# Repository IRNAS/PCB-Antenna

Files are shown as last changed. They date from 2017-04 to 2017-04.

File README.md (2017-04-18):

# PCB Antenna
#### Compact Wideband Omnidirectional UHF Antenna for TV White Space Cognitive Radio Application

This repository contains the design files for PCB antenna. PCB Antena is described in the [given PDF][link1_paper_PDF], and it is designed using [Altium designer EDA tool][link2_altium].

For more information about the design of the antenna please see the **[Schematics and PCB design files in PDF format][link3_design_PDF]**.

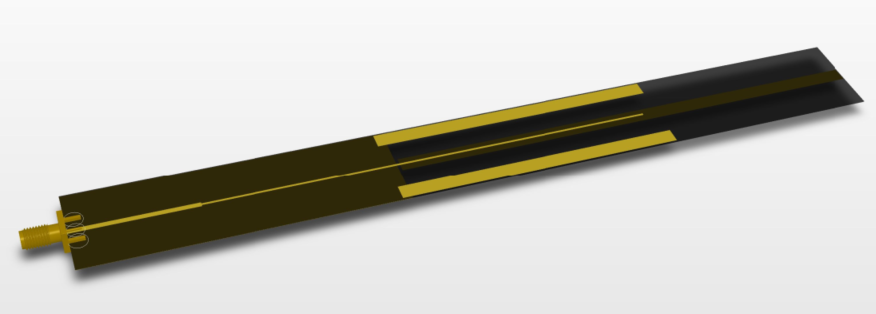
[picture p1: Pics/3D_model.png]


---

#### License

All our projects are as usefully open-source as possible.

Hardware including documentation is licensed under [CERN OHL v.1.2. license](http://www.ohwr.org/licenses/cern-ohl/v1.2)

Firmware and software originating from the project are licensed under [GNU GENERAL PUBLIC LICENSE v3](http://www.gnu.org/licenses/gpl-3.0.en.html).

Open data generated by our projects is licensed under [CC0](https://creativecommons.org/publicdomain/zero/1.0/legalcode).

All our websites and additional documentation are licensed under [Creative Commons Attribution-ShareAlike 4 .0 Unported License] (https://creativecommons.org/licenses/by-sa/4.0/legalcode).

What this means is that you can use hardware, firmware, software and documentation without paying a royalty and knowing that you'll be able to use your version forever. You are also free to make changes but if you share these changes then you have to do so on the same conditions that you enjoy.

Koruza, GoodEnoughCNC, and IRNAS are all names and marks of Institut IRNAS Race. 
You may use these names and terms only to attribute the appropriate entity as required by the Open Licences referred to above. You may not use them in any other way and in particular, you may not use them to imply endorsement or authorization of any hardware that you design, make or sell.

[link1_paper_PDF]: https://github.com/IRNAS/PCB-Antenna/blob/master/Docs/Design%20guide/manuscript.pdf
[link2_altium]: http://www.altium.com/
[link3_design_PDF]: https://github.com/IRNAS/PCB-Antenna/blob/master/pcb-antenna-PCB/Project%20Outputs%20for%20PCB_Project/pcb_antenna.PDF

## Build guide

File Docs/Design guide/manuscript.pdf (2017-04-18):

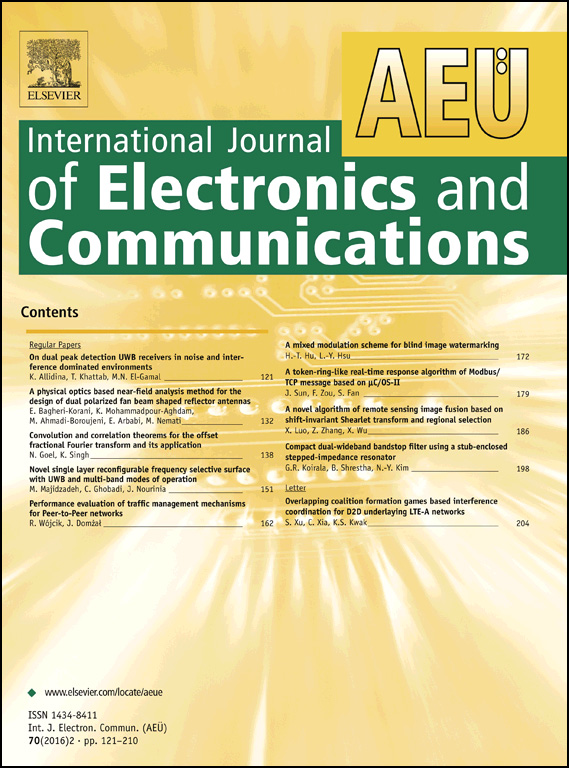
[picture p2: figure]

# Accepted Manuscript

# Short communication

# Compact Wideband Omnidirectional UHF Antenna for TV White Space Cognitive Radio Application

# Naizhi Wang, Yue Gao, Qingsheng Zeng

PII: | S1434-8411(16)30990-6
DOI: | http://dx.doi.org/10.1016/j.aeue.2017.02.011
Reference: | AEUE 51803
To appear in: | International Journal of Electronics and Communi-
| cations
Received Date: | 23 November 2016
Revised Date: | 16 January 2017
Accepted Date: | 12 February 2017

Please cite this article as: N. Wang, Y. Gao, Q. Zeng, Compact Wideband Omnidirectional UHF Antenna for TV White Space Cognitive Radio Application, International Journal of Electronics and Communications (2017), doi:

# http://dx.doi.org/10.1016/j.aeue.2017.02.011

This is a PDF file of an unedited manuscript that has been accepted for publication. As a service to our customers we are providing this early version of the manuscript. The manuscript will undergo copyediting, typesetting, and review of the resulting proof before it is published in its final form. Please note that during the production process errors may be discovered which could affect the content, and all legal disclaimers that apply to the journal pertain.

1

### Compact Wideband Omnidirectional UHF Antenna for TV White Space

### Cognitive Radio Application

### Naizhi Wang¹*, Yue Gao²

### , Qingsheng Zeng³,4

1
The 14th Research Institute of China Electronics Technology Group Corporation, Nanjing

210039, P. R. China, e-mail: naizhiwang@hotmail.com

2
School of Electronic Engineering and Computer Science, Queen Mary University of

London, London E1 4NS, U.K.

3
School of Physics and Electronic Engineering, Shanxi University, Taiyuan 030006, P. R.

China

4
School of Electrical Engineering and Computer Science, University of Ottawa, Ottawa

K1N 6N5, Canada

*
Corresponding author

This paper presents design and analysis of a compact wideband omnidirectional antenna for application in

TV white space cognitive radio. The proposed antenna mainly consists of a monopole, a pair of parasitic

elements, and a brief impedance matching network, all etched on an FR4 substrate. To obtain physical

insight, an equivalent circuit is modelled and analysed to reveal the contribution of each part of the

antenna to its bandwidth enhancement. Performance of the antenna is evaluated by simulations, and then

further validated by experiments. Experimental results show that the antenna has an impedance bandwidth

(voltage standing wave ratio less than 2) ranging from 460 MHz to 870 MHz, as well as omnidirectional

radiation patterns in H-plane through the whole band.

Key words: TV white space, cognitive radio, wideband UHF antenna, omnidirectional radiation.

### 1. Introduction

With the ability of spectrum-sensing, cognitive radio is an attractive technology to make efficient use of

radio spectrum [1]. Presently, analogue television broadcasts are being switched off and replaced by more

spectrally efficient digital television transmissions in many countries [2]. The white spaces existing in the

UHF TV band (470 MHz - 790 MHz in ITU Region 1) have good propagation and building penetration

characteristics. Therefore, TV white spaces (TVWS) are competent to provide long distance broadband

2

wireless access to population in rural area by virtue of the technology of cognitive radio [3]. For effective

detection and allocation of TVWS, antennas with operating frequency from 470 MHz to 790 MHz and

omnidirectional radiation patterns are required.

Several antennas with electrical performances suitable for the aforementioned application have

been designed. A printed U-shaped monopole with meandering structure and a printed spline-shaped one

with shorting stub are reported in [4] and [5], respectively, both with dimensions over 170 mm × 160 mm.

Reconfigurable antennas [6, 7] can be more compact, whereas they are complex in retuning to cover the

whole UHF TV band. The antennas reported in [8] and [9] are with lumped matching components, leading

to enhanced impedance bandwidth while sacrificing the efficiency.

In this paper, we present a new design of a wideband omnidirectional antenna for TV white space

cognitive radio application. The antenna is etched on an FR4 substrate with a compact strip profile.

Explicit analysis with an equivalent circuit is performed for in-depth understanding of the wide band

characteristic. Simulations and measurements are also carried out to evaluate and validate the electrical

performance.

### 2. Antenna design

General configuration of the proposed antenna is described in Fig. 1. It is evolved from a printed

monopole, to which a pair of parasitic elements and a brief matching network are added for bandwidth

enhancement. All of the three parts are etched on an elongate FR4 substrate (-

=4.4, =0.02) with a

dimension of 261 mm × 30 mm × 0.8 mm. Excitation is realized by means of coupling energy from the

microstrip line to the antenna through the gap Wg. Detailed dimensions of the antenna are listed in Table 1.

Fig. 2 shows the fabricated prototype of the antenna. An elaborate aluminium fixture is used to

fasten a 50-Ohm SMA connector to the feed line of the antenna, and further to fix the entirety onto a

turntable during the measurement process.

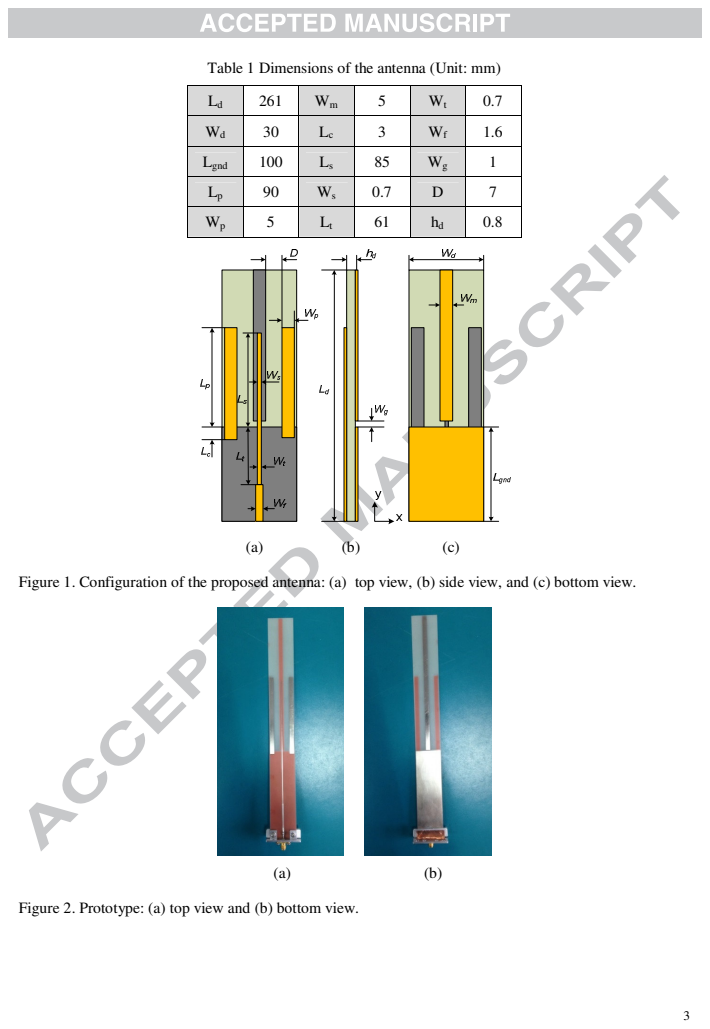
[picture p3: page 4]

Table 1 Dimensions of the antenna (Unit: mm)

Lgnd | 100 | Ls | 85 | Wg | 1

Figure 1. Configuration of the proposed antenna: (a) top view, (b) side view, and (c) bottom view.

Figure 2. Prototype: (a) top view and (b) bottom view.

4

### 3. Equivalent circuit and analysis

The antenna being capable of working within a large bandwidth is attributed to the parasitic elements and

the brief impedance matching network. To reveal the contribution of each part, the antenna is modelled as

an equivalent circuit in Fig. 3, and then analysed by the aid of Smith Chart.

Figure 3. Equivalent circuit of the proposed antenna.

The monopole equates to a complex impedance with a value of Z = R + jX, so do the parasitic

elements to one with Z' = R' + jX'. They are in parallel, since the parasitic elements are driven by energy

coupled from the monopole. Line stub Ls is modelled as a segment of open-ended transmission line with

electrical length L1 and characteristic impedance Zc1, while line Lt is modelled as one with electrical

length L2 and characteristic impedance Zc2, respectively. Line Wf

is the feed line with characteristic

impedance Zc3 = 50 Ohm.

Firstly, take only the monopole into consideration by eliminating the parasitic elements and the

transmission lines. We add an excitation voltage to the gap Wg and have the monopole calculated. The

resulting input impedance Z = R + jX from 470 MHz to 790 MHz is plotted as curve 1 (solid green) in Fig.

4a. Note that the lower frequency end locates at the position of the figure notation. The curve on Smith

Chart shows that values of Z versus frequency vary over a wide range, making it difficult to realize

impedance matching through the whole band. Secondly, add the parasitic elements to the monopole. Curve

2 (dotted red) in Fig. 4a presents the calculated value of Z ǁ Z'. It can be observed that, as a result of the

5

parallelization, the input impedance curve further curls inward and is closer to the matching point of Smith

Chart. Both values of the resistance and the reactance decrease, and now each varies in a minified range.

The bottom part Lc of each parasitic element overlaps with the ground plane, providing additional

capacitance, and sequentially reducing the length of each parasitic element which ensures that they will

not bring serious impact on radiation patterns in H-plane.

To further minify the reactance of curve 2, a line stub Ls, which is capacitive in the lower band and

inductive in the higher, is added in series. The input impedance changes to Zin = Z ǁ Z' + Zstub, represented

by curve 3 (solid blue) in Fig. 4b. Curve 3 retains the real part of curve 2 because Zstub is purely reactive.

In the next, the input impedance is transformed to Zt by the microstrip line Lt. Curve 4 (solid purple) in

Fig. 4b represents the input impedance Zt, which already satisfies the requirement of voltage standing

wave ratio (VSWR) less than 2 through the band from 470 MHz and 790 MHz.

(a) (b)

Figure 4. Impedance matching to 50 Ohm: (a) function of the parasitic elements and (b) function of the

cascaded transmission lines.

6

### 4. Simulations and measurements

Based on the previously analysis, an antenna used for TV white space cognitive radio application is

engineered and optimized, followed by fabrication. The top view and the bottom view of the prototype are

shown in Fig. 2. Its performance is evaluated in an anechoic chamber with a vector network analyzer and a

far-field antenna measurement system.

Comparisons between simulations and measurements are carried out to validate the performance.

Fig. 5 plots simulated and measured VSWRs of the antenna. The measured result indicates that the

antenna works well with VSWR less than 2 over 460 MHz to 870 MHz, whereas the simulated impedance

bandwidth is from 465 MHz to 840 MHz. Though small discrepancies exist, which are probably caused by

the aluminium fixture, these two results agree well with each other. Normalized radiation patterns at 500

MHz and 790 MHz are plotted in Fig. 6. It can be observed that the patterns are omnidirectional in H-

plane (xoz) and have nulls in E-plane (yoz), similar to those of classic monopole antennas. Radiation gain

in H-plane is also measured and plotted in Fig. 7 with the simulated one. Due to influence of the cable and

the turntable, maximum radiation does not occur in H-plane at lower frequencies, as shown in Fig. 6b,

resulting in the measured gain lower than the simulated one as presented in Fig. 7.

400 450 500 550 600 650 700 750 800 850 900

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
Measurement
Simulation

VSWR

Frequency (MHz)

Figure 5. Voltage standing wave ratio (VSWR).

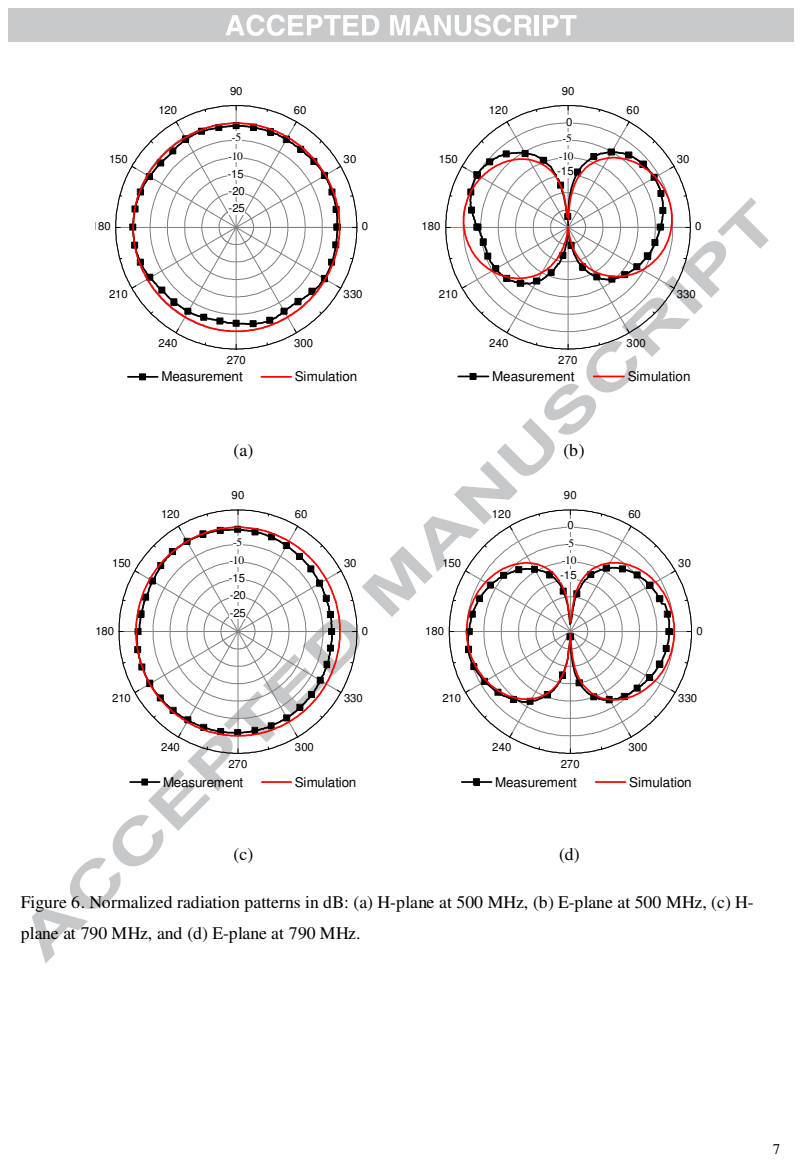
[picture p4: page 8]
Measurement; Simulation

Figure 6. Normalized radiation patterns in dB: (a) H-plane at 500 MHz, (b) E-plane at 500 MHz, (c) H-

plane at 790 MHz, and (d) E-plane at 790 MHz.

8

400 450 500 550 600 650 700 750 800 850 900

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
Gain (dBi)

Frequency (MHz)

Measurement
Simulation

Figure 7. Radiation gain in H-plane.

### 5. Conclusion

A printed antenna working in the UHF TV band (470 MHz - 790 MHz) has been designed for the TV

white space cognitive radio application. It is with a compact strip profile, good impedance matching,

omnidirectional radiation patterns and stable gain through the frequency band of interest. The

experimental results coincide with the simulated ones, having the excellent performance validated. All the

features make the antenna a competent candidate for TV white space cognitive radio application. In

addition, the bandwidth enhancement approach is revealed by modelling the antenna as an equivalent

circuit and analysing the circuit by the aid of Smith Chart. This analysis will facilitate future designs of

such antennas.

### 6. Acknowledgement

The authors would like to acknowledge the Engineering and Physical Sciences Research Council

(EPSRC) in the UK for funding the work under Grant No. EP/L024241/1.

9

References

[1] Ren X, Chen C. Spectrum sensing algorithm based on sample variance in multi-antenna cognitive

radio systems. AEU-Int J Electron C 2016; 70(12): 1601-1609.

[2] Holland O, Ping S, Aijaz A, et al. To white space or not to white space: That is the trial within the

Ofcom TV white spaces pilot. 2015 IEEE International Symposium on Dynamic Spectrum Access

Networks; 2015 Sep 29 - Oct 2; Stockholm, Sweden.

[3] Qin Z, Gao Y, Plumbley M, et al. Wideband Spectrum Sensing on Real-time Signals at Sub-Nyquist

Sampling Rates in Single and Cooperative Multiple Nodes. IEEE T Signal Proces 2015; 64(12):3106-

3117.

[4] John M, Ammann MJ. A Compact Shorted Printed Monopole Antenna for TV White Space Trials. The

7th European Conference on Antennas and Propagation-EuCAP; 2013 Apr 8-14; Gothenburg, Sweden.

[5] Jamaluddin MH, Rahman TA, Mohamad H, et al. Wideband Planar U-shaped Monopole Antenna with

Meandering Technique for TV White Space Application. Radioengineering 2013; 22(3): 708-713.

[6] Bao XL, Shynu SV, Ammann MJ. Design of a Tunable Compact Antenna for Digital Video

Broadcasting Handheld Terminals. 2009 Loughborough Antennas & Propagation Conference; 2009

Nov 16-17; Loughborough, UK.

[7] Choi DH, Im YT, Cho YJ, et al. A Tunable Antenna for DVB-H Applications. IEEE Antenn Wirel Pr

2007; 6: 515-517.

[8] Liang X, Jin R, Zhao Y, et al. Compact DVB-T printed monopole antenna. 2010 International

Workshop on Antenna Technology; 2010 Mar 1-3; Lisbon, Portugal.

[9] Bod M , Ahmadi-Boroujeni M, Mohammadpour-Aghdam K. Broadband loaded monopole antenna

with a novel on-body matching network. AEU-Int J Electron C 2016; 70(11): 1551–1555.

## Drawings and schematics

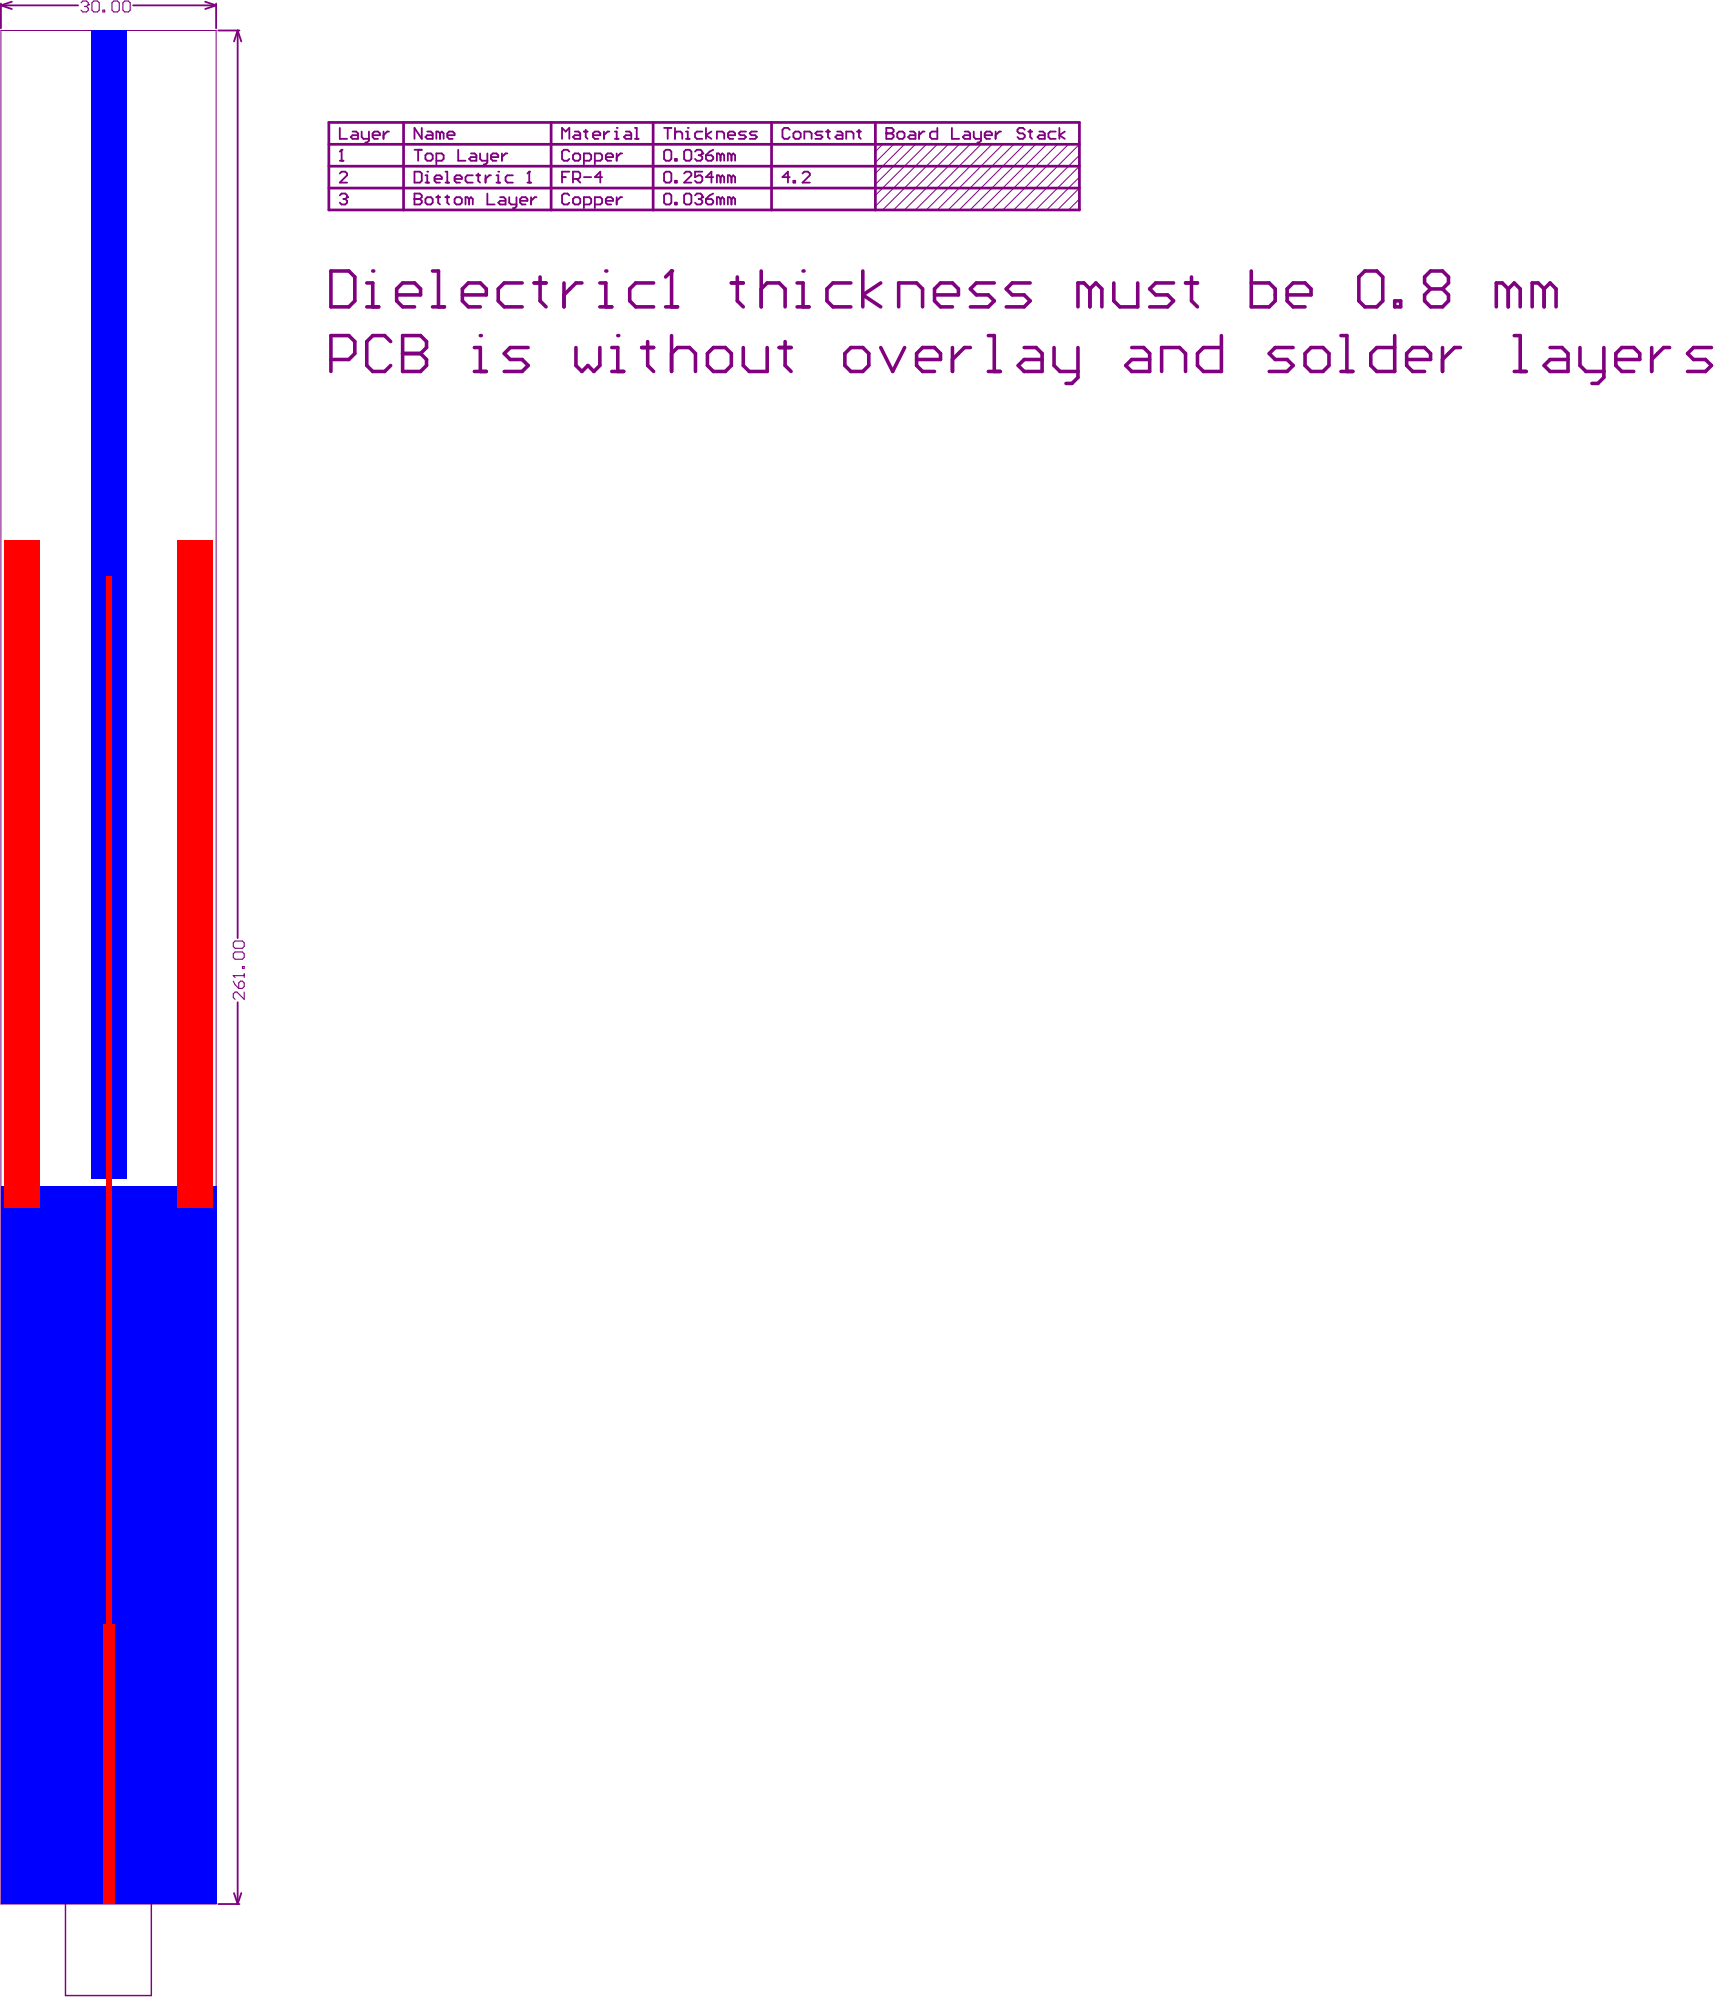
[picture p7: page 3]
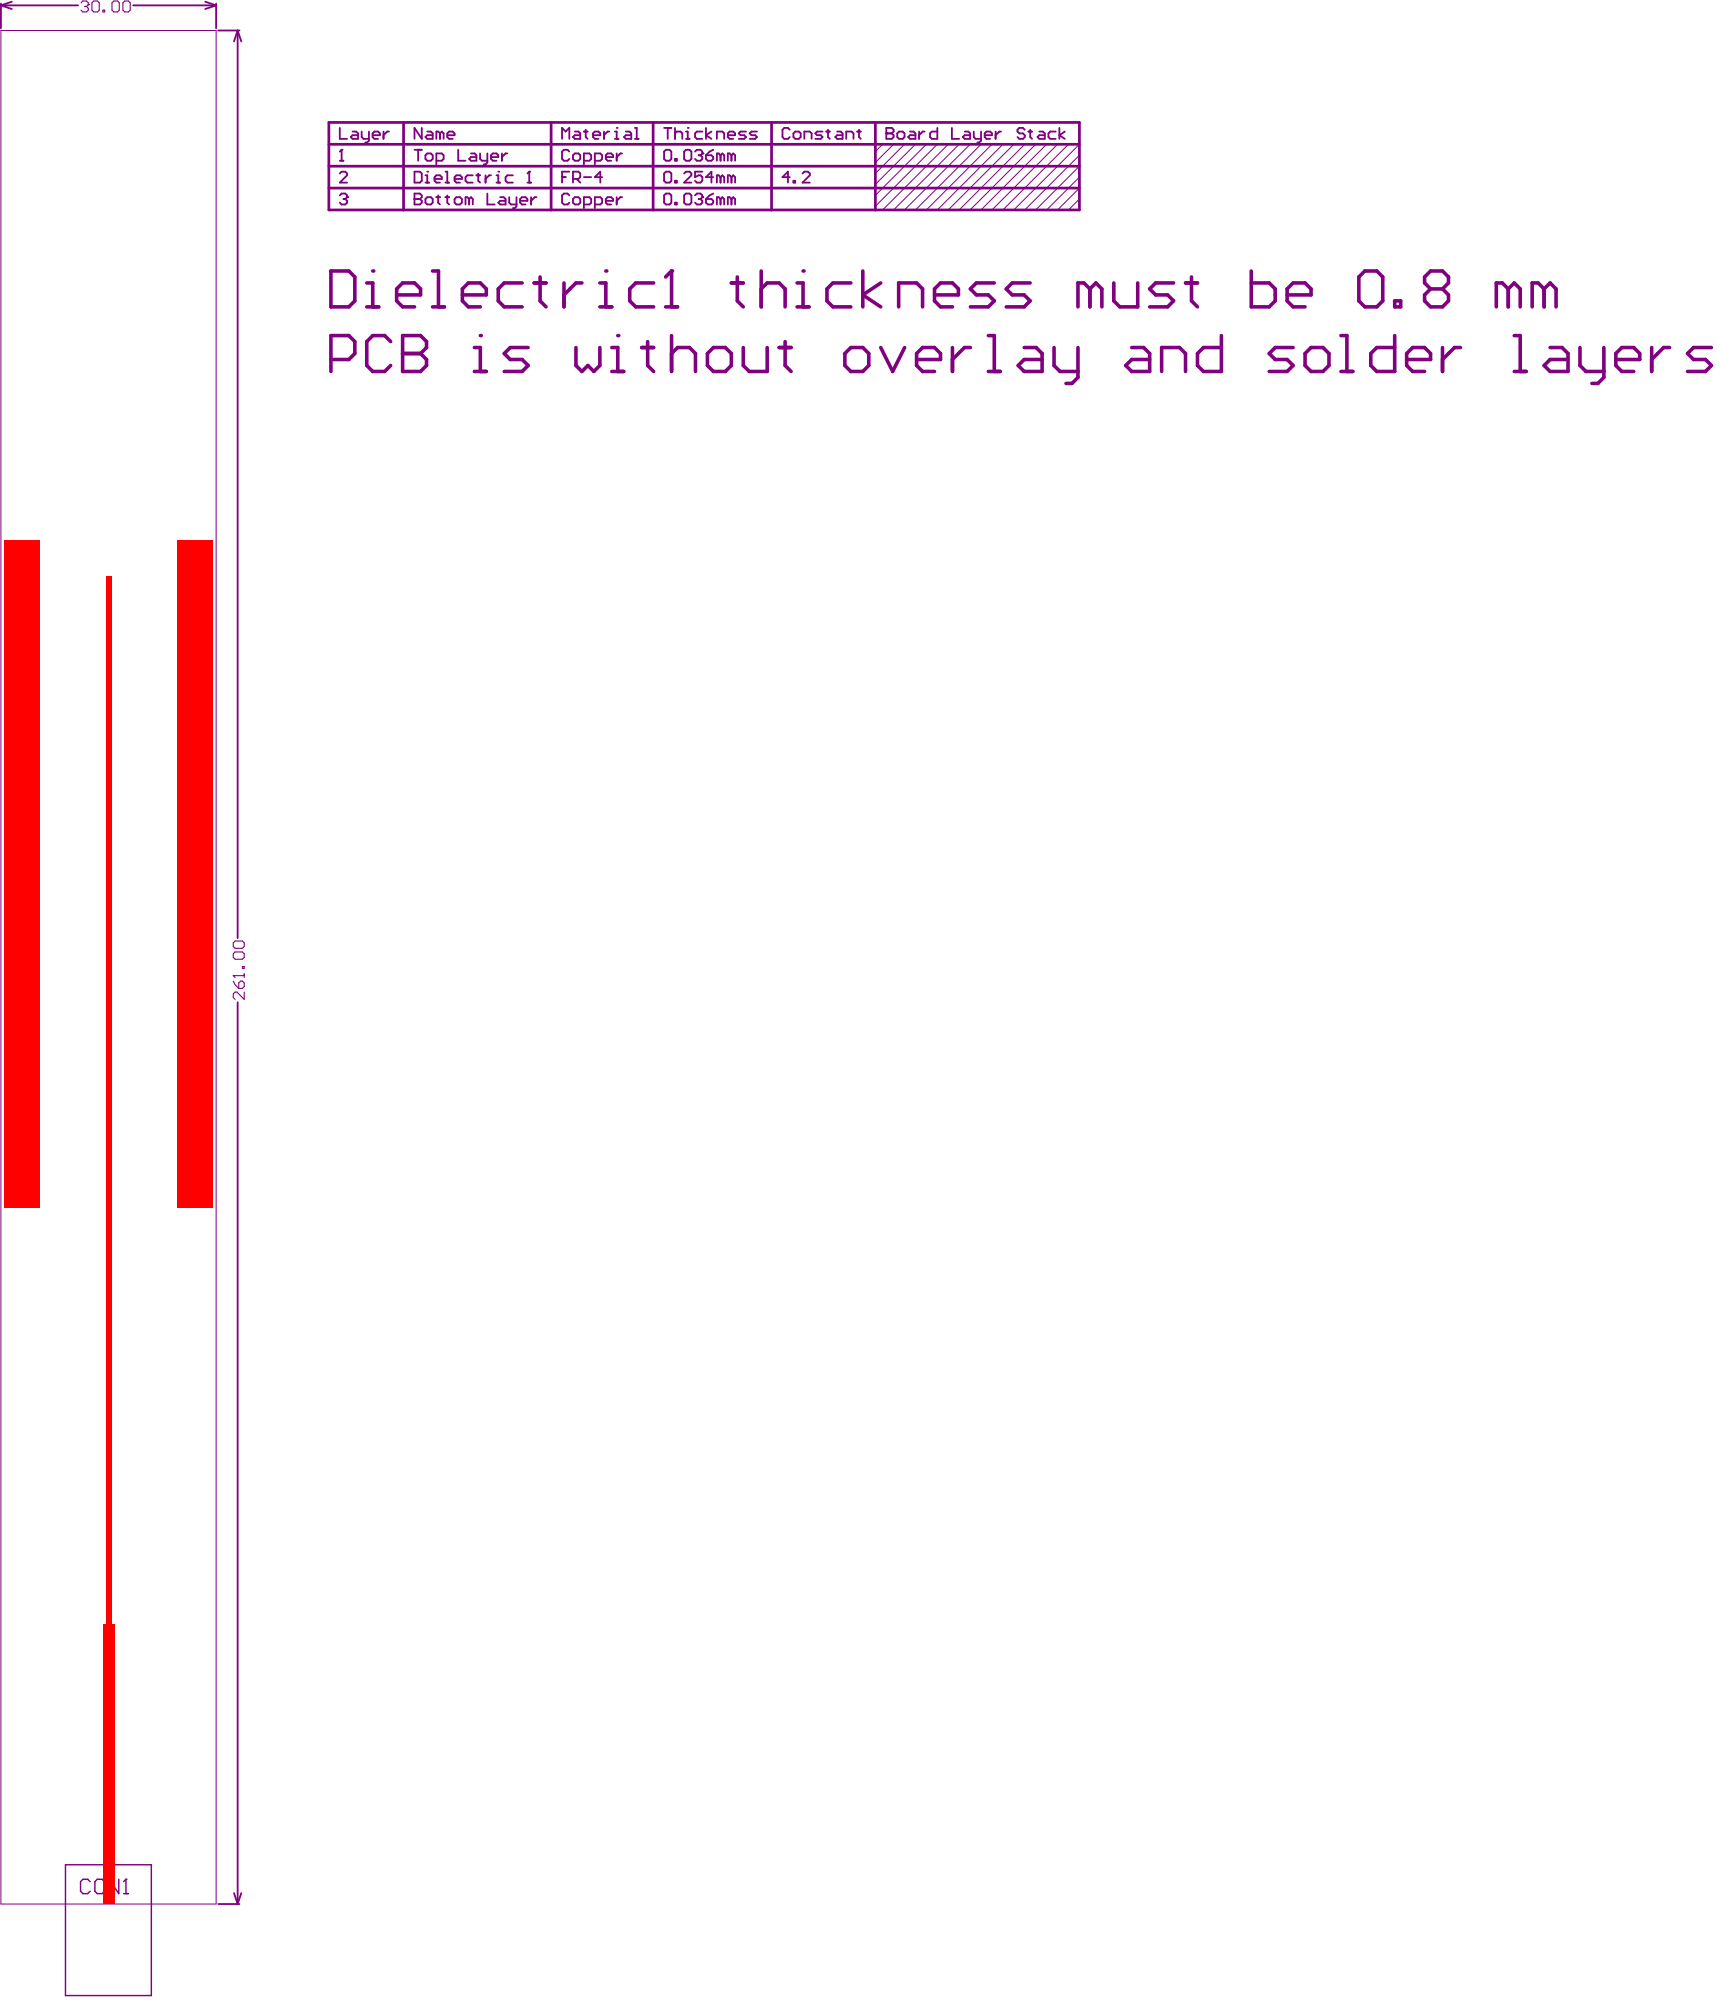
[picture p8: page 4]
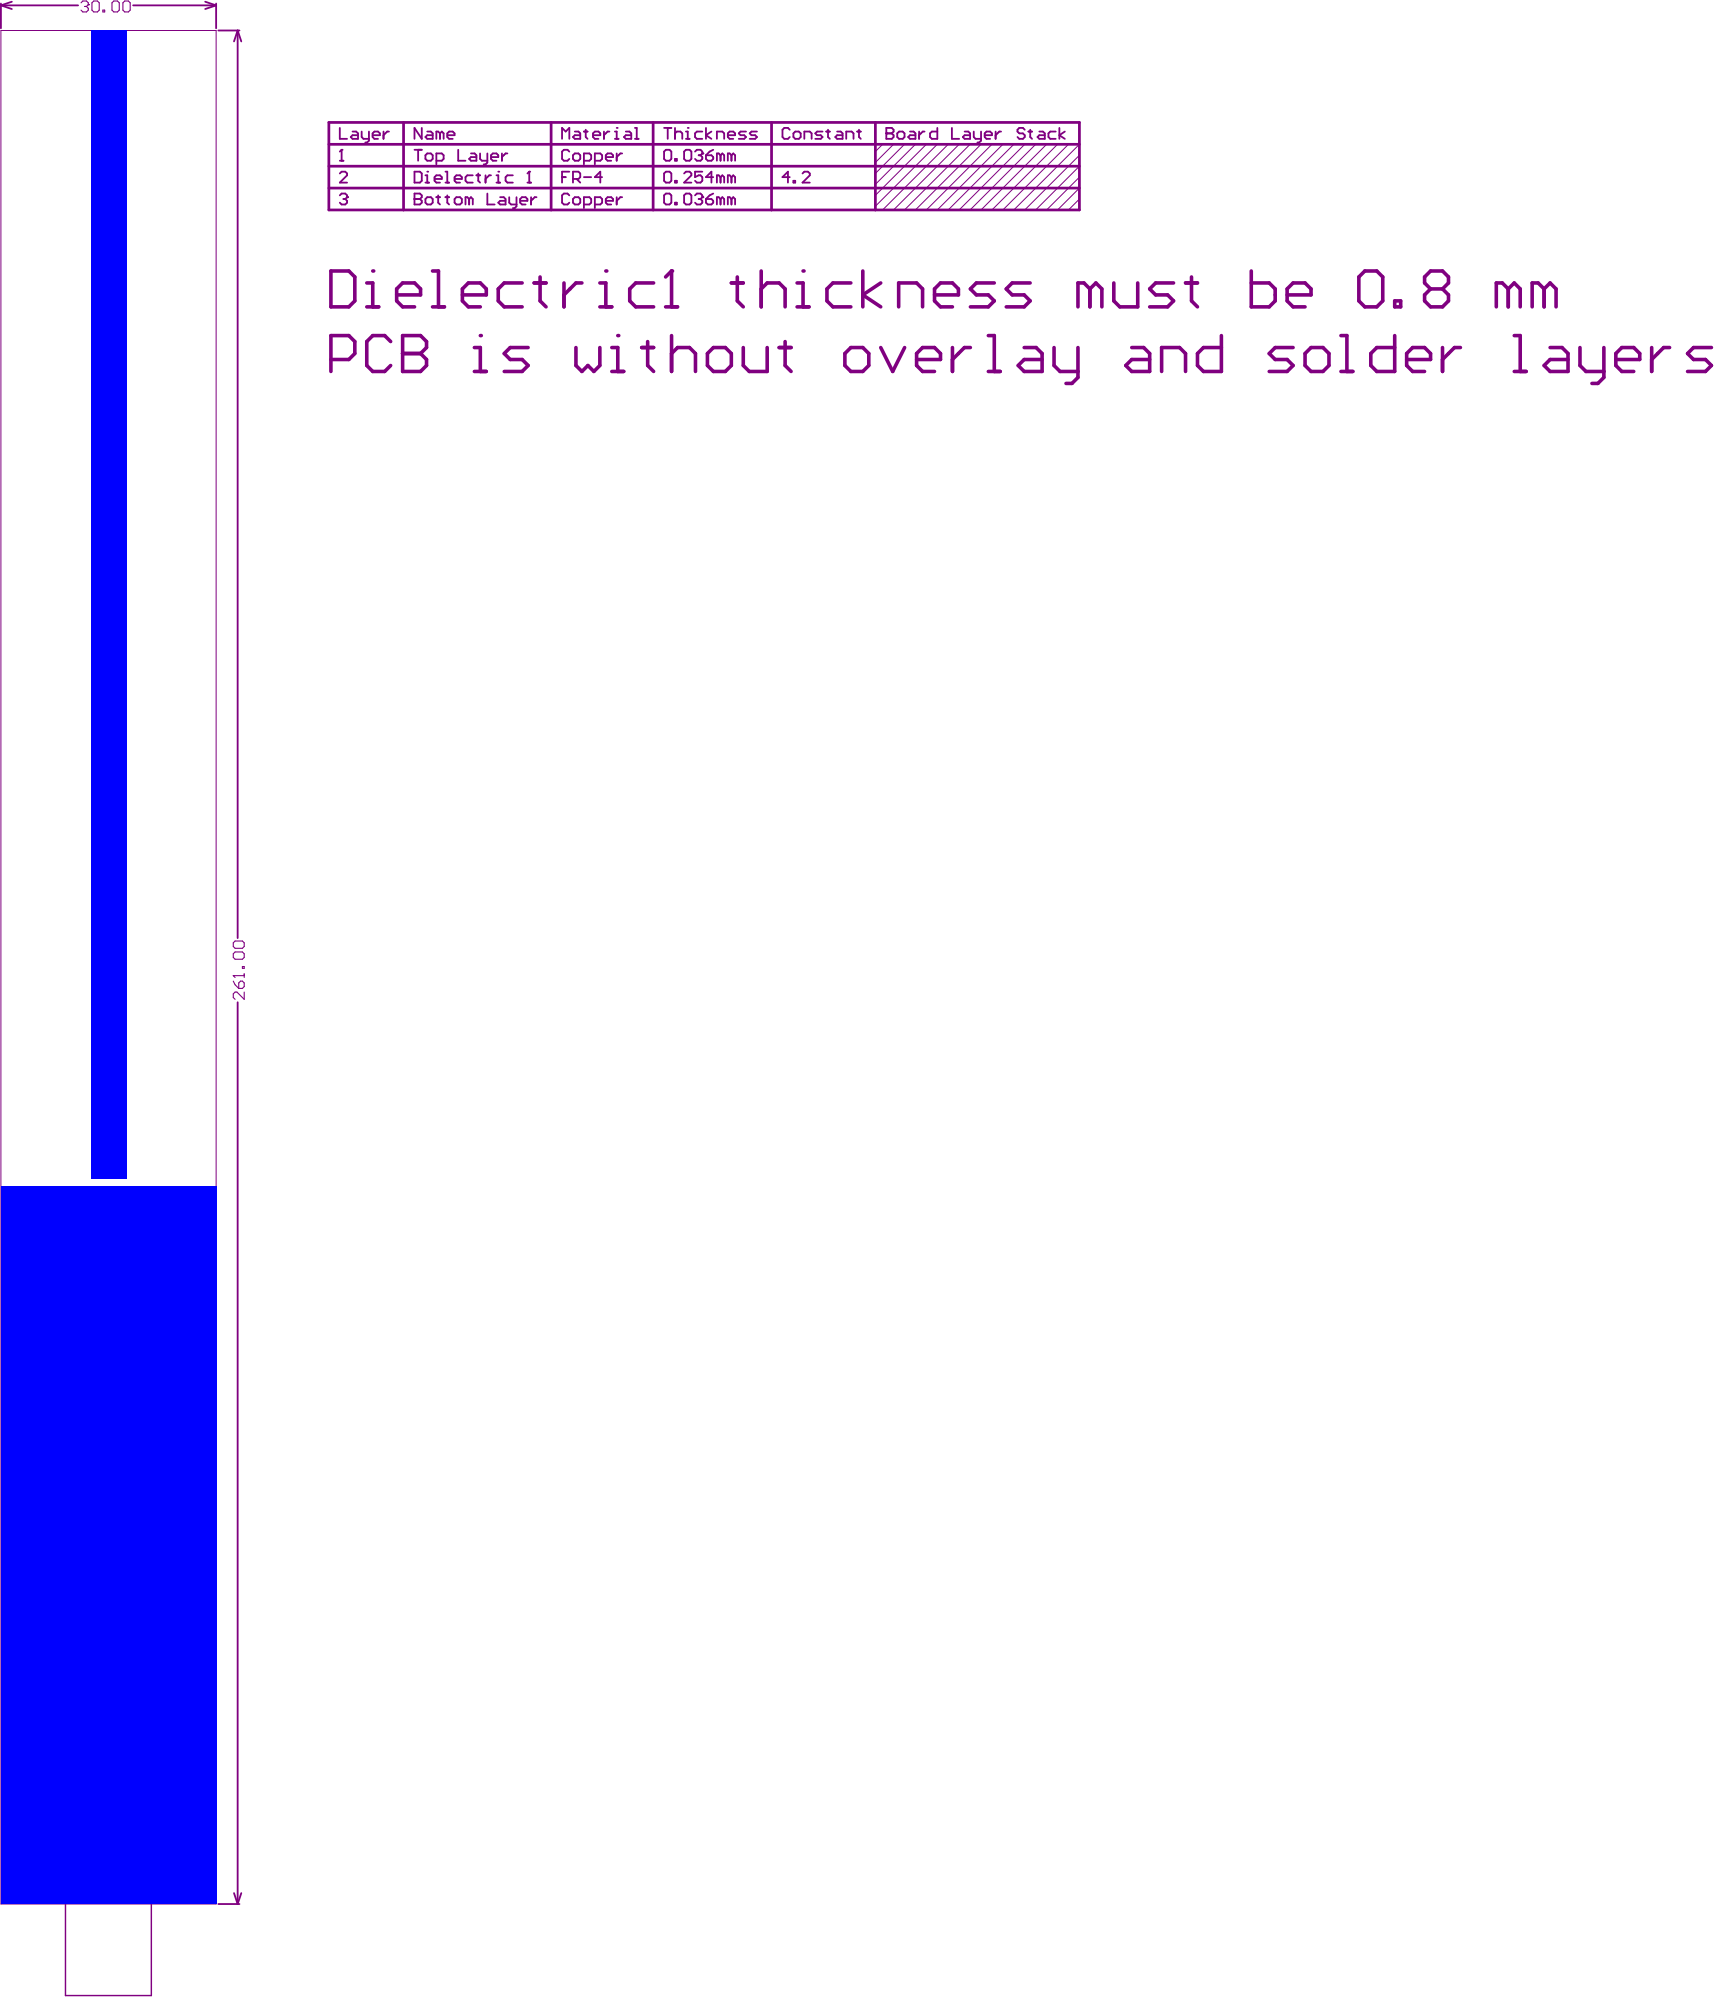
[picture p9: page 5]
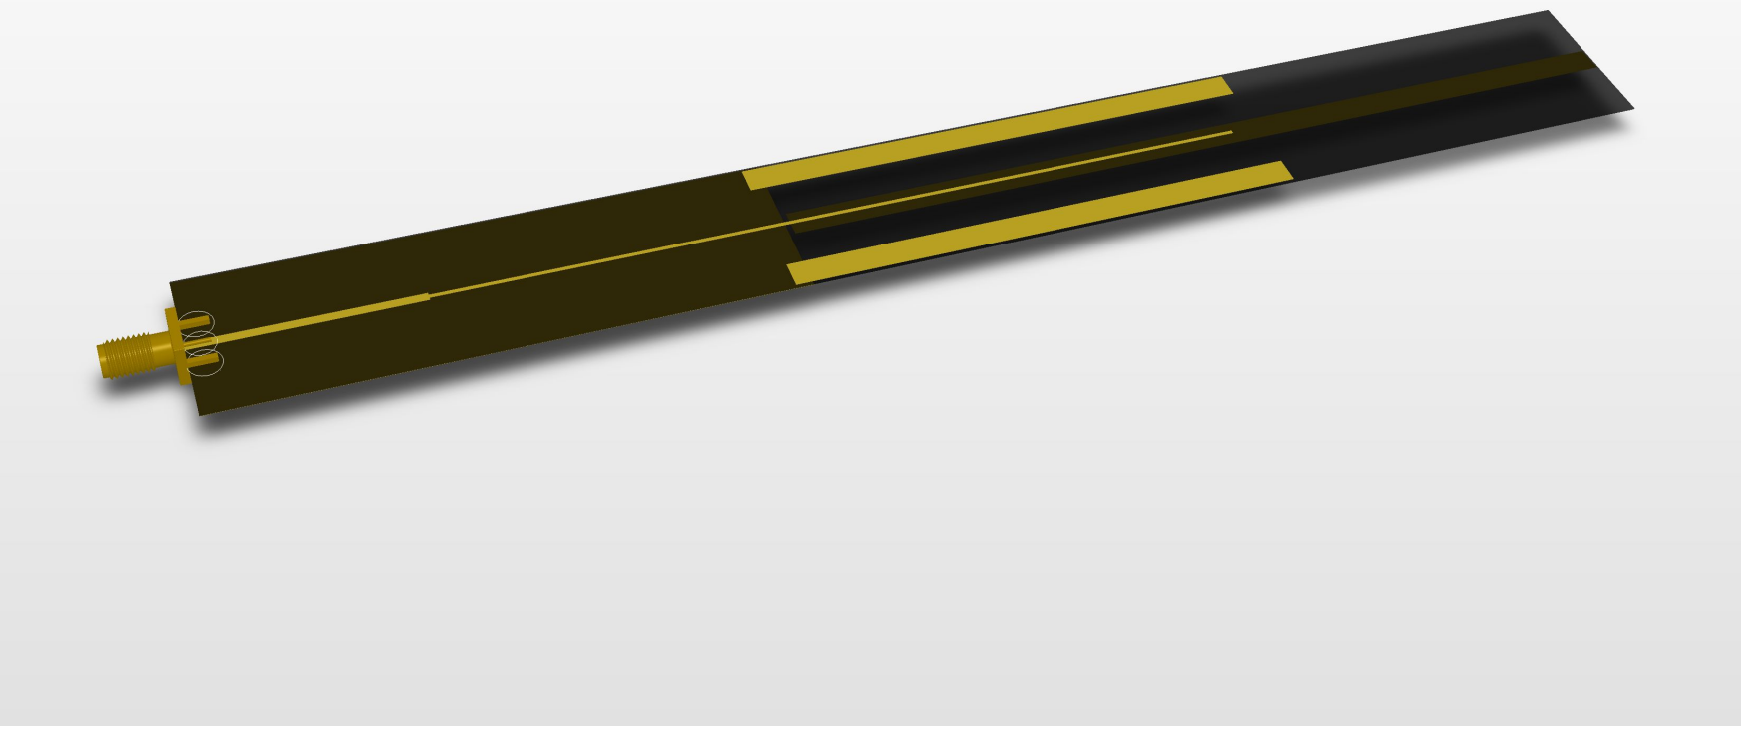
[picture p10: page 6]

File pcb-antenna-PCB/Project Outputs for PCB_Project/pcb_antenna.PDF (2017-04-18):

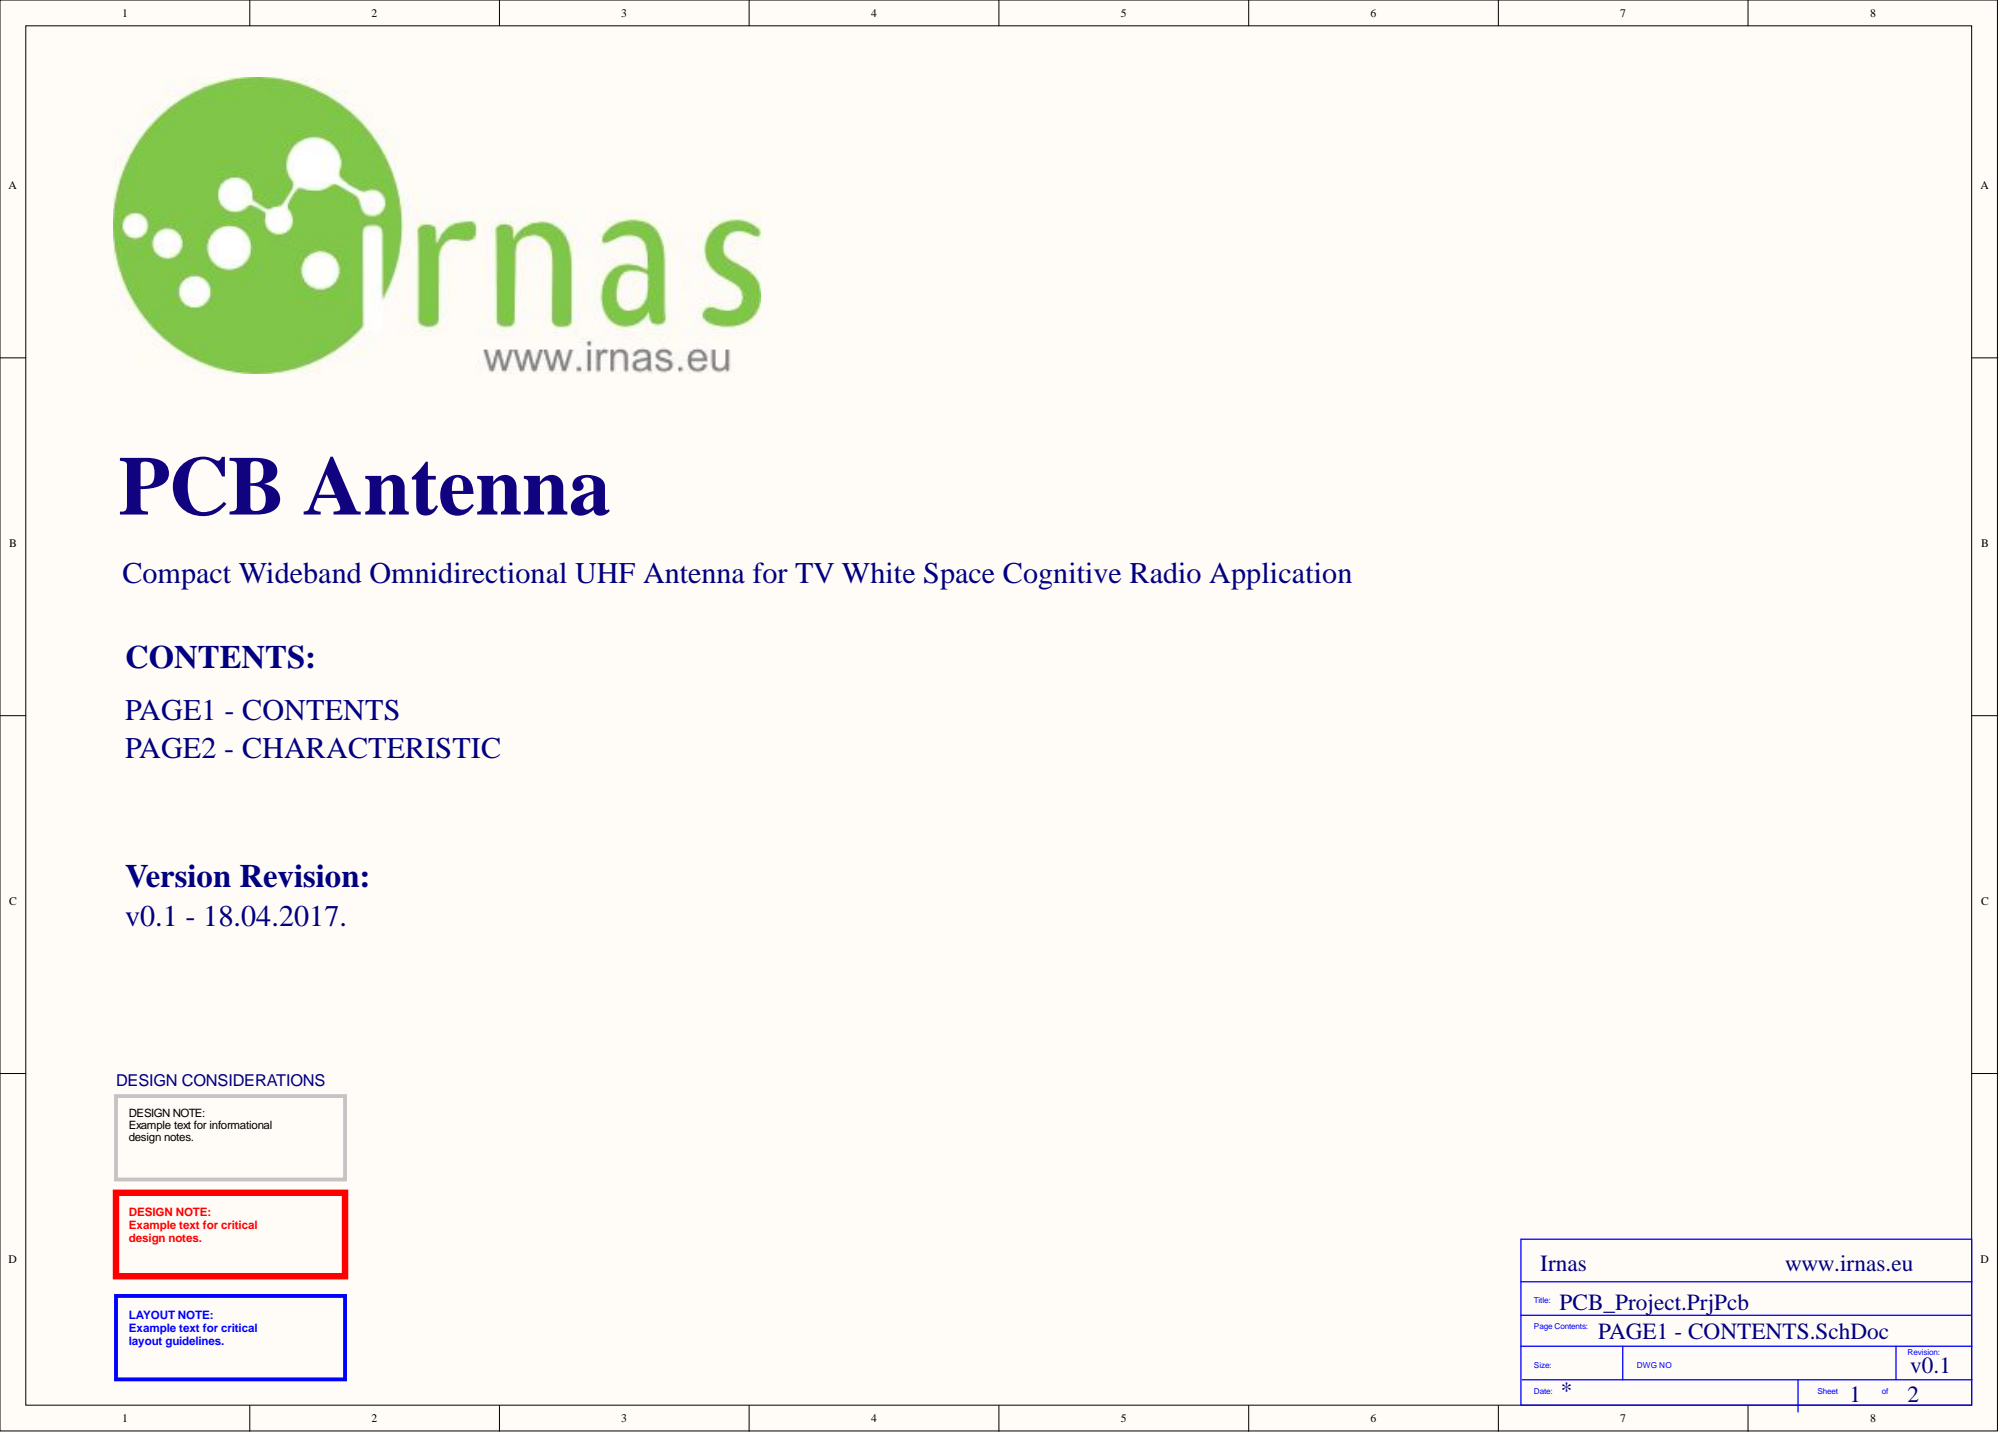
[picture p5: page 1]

Compact Wideband Omnidirectional UHF Antenna for TV White Space Cognitive Radio Application

DESIGN NOTE:
Example text for informational
design notes.

Example text for critical

LAYOUT NOTE:
layout guidelines.

Size: | DWG NO | Revision: v0.1

* Date: | 1 2 Sheet of

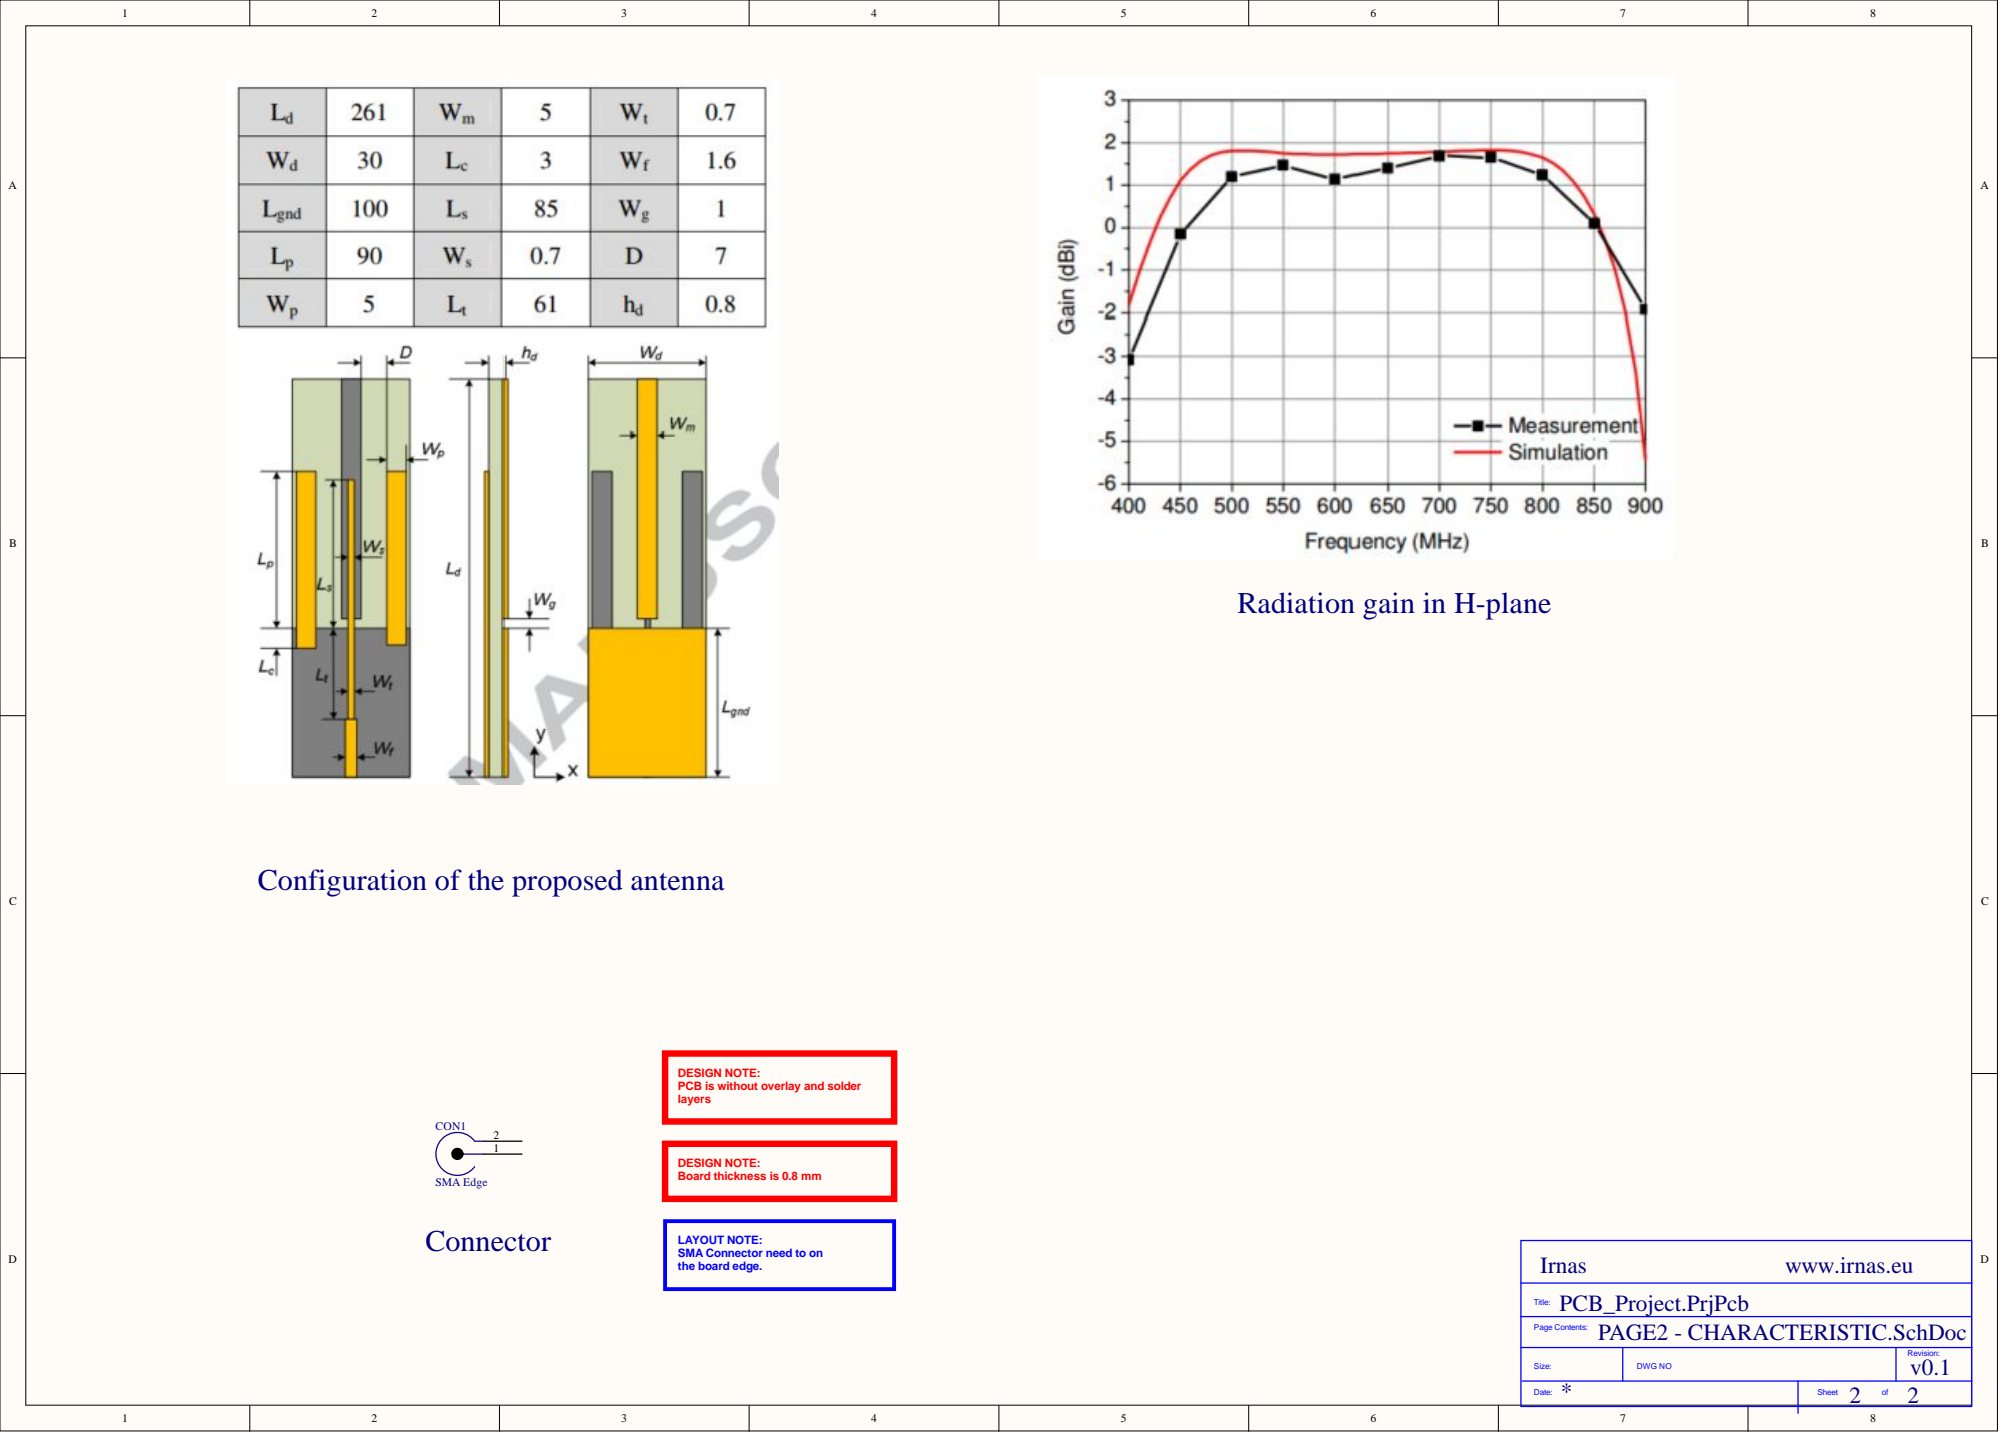
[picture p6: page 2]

Radiation gain in H-plane

Configuration of the proposed antenna

DESIGN NOTE:
PCB is without overlay and solder
layers

Board thickness is 0.8 mm

LAYOUT NOTE:
SMA Connector need to on
the board edge.

Size: | DWG NO | Revision: v0.1

* Date: | 2 2 Sheet of
